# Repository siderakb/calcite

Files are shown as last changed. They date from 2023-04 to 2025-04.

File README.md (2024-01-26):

# Calcite

calcite52

Kailh Choc V1 (aka PG1350) low profile switches ortho keyboard, includes PCB and CNC/3DP case, inspired by [ARTSEY](https://artsey.io/), [Home row mods](https://precondition.github.io/home-row-mods) and Preonic/Planck keyboard. 

> The keycap in the above picture is from Keychron K1 v2.

## Note

Gerber, BOM and CPL files are generated by [KiCad JLCPCB Tools](https://github.com/Bouni/kicad-jlcpcb-tools) plugin.  

I use [KiCAD KLE Placer](https://github.com/zykrah/kicad-kle-placer) plugin to automatically place switch footprints.

If `key-switches.pretty` folder is empty, use `git submodule update --init` to clone submodule.

## Disclaimer

These files are provided without warranty of any kind.  
It is recommended to check yourself before manufacturing and use.

For the full statement, plase see [LICENSE](./LICENSE).

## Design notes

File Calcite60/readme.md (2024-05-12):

# Calcite60



A 60 keys ortho Kailh Choc V1 keyboard.

- Preonic V3 compatible (Mounting holes, USB and RESET button).
- Kailh Choc V1 low profile switches (PG1350), optional 2U keys.
- USB Type-C with ESD protection and resettable fuse.
- RP2040 ARM MCU, 16MB external flash.
- One configurable monochrome LED indicator.
- Powered by [QMK](https://github.com/qmk/qmk_firmware) firmware.
- Support [Vial](https://get.vial.today), edit keymap and configure keyboard in real time.
- JLCPCB's PCBA service available.

## PCB

Online preview available [here](https://kicanvas.org/?github=https%3A%2F%2Fgithub.com%2Fsiderakb%2Fcalcite%2Ftree%2Fmain%2FCalcite60%2Fpcb), powered by [KiCanvas](https://kicanvas.org/)

| | Preview |
| --- | :---: |
| Front  |  |
| Back |  |
| Layers |  |

### Board Characteristics

- Copper layer count: 2
- Board thickness: 1.6 mm
- Board overall dimensions: 226 mm x 94.15 mm
- Min track/spacing: 0.13 mm / 0.13 mm
- Min hole diameter: 0.3 mm
- Castellated pads: No
- Edge card connectors: No
- Plated board edge: No

## Screw

- 4* M2x2~4, 90° flat head

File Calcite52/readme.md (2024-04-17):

# Calcite52

calcite52

- 52 keys ortho keyboard.
- Kailh Choc V1 low profile switches (PG1350).
- USB Type-C with ESD protection and resettable fuse.
- RP2040 ARM MCU, 16MB external flash.
- One configurable monochrome LED indicator.
- M2 screw mounting holes.
- USB D+/- pads for debugging.
- Powered by [QMK](https://github.com/qmk/qmk_firmware) firmware.
- Support [Vial](https://get.vial.today), edit keymap and configure keyboard in real time.
- JLCPCB's PCBA service available.

## PCB

PCB online preview avaliable [here](https://kicanvas.org/?github=https%3A%2F%2Fgithub.com%2Fsiderakb%2Fcalcite%2Ftree%2Fmain%2FCalcite52%2Fpcb), powered by KiCanvas.

| | Preview |
| :----: | :---: |
| Front  |  |
|  Back  |  |
| Layers |  |

### Board Characteristics

- Copper layer count: 2
- Board thickness: 1.6 mm
- Board overall dimensions: 231.14 mm x 97.79 mm
- Min track/spacing: 0.13 mm / 0.13 mm
- Min hole diameter: 0.3 mm
- Castellated pads: No
- Edge card connectors: No
- Plated board edge: No

## Case

- CNC: Designed using [onshape](https://cad.onshape.com/documents/40c7e2089f3d168efe6af68a/w/3670640f6bf03c896decab1c/e/fe064372e5ac08dff53a3881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). I order aluminum 6061 + bead blast + anodized from PCBWay around 60 USD (June 2023).
- 3D Printing: Designed using FreeCAD. Please note that the 3D printed casing will bend easily and is not recommended.

## Firmware

Vial QMK firmware is available in [siderakb/vial-qmk repo](https://github.com/siderakb/vial-qmk/tree/siderakb/main/keyboards/siderakb/calcite52) (*siderakb/main* branch).

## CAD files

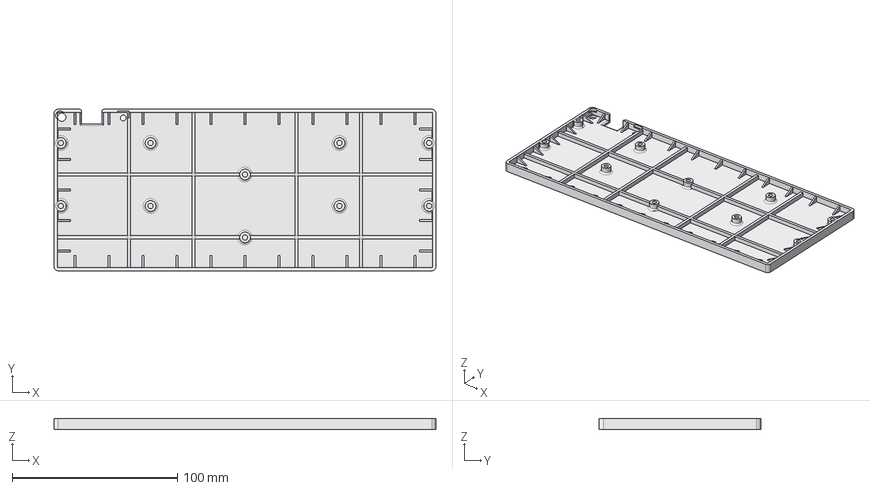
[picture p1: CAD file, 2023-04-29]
Calcite52/case/3dp/Calcite52_3dp_case.FCStd
231.1 x 97.8 x 6.50 mm

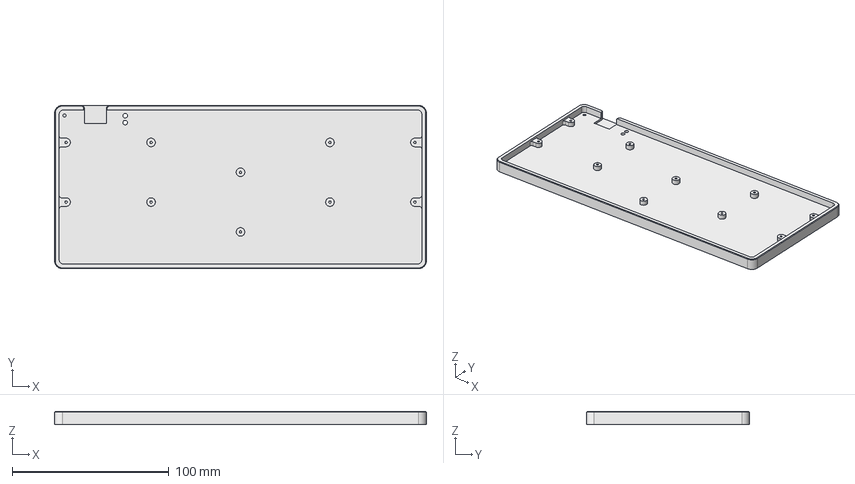
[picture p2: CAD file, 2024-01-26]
Calcite52/case/cnc/Calcite52_cnc_case.step
237.6 x 104.3 x 8.50 mm

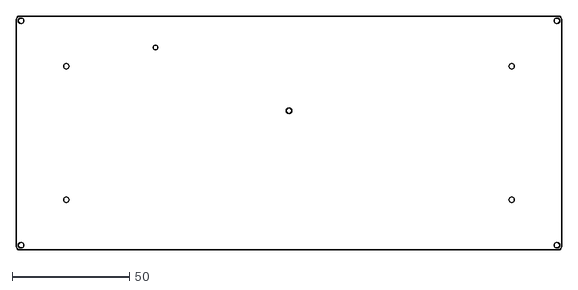
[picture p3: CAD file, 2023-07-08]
Calcite60/case/calcite60_case_bottom.dxf
232.8 x 99.8

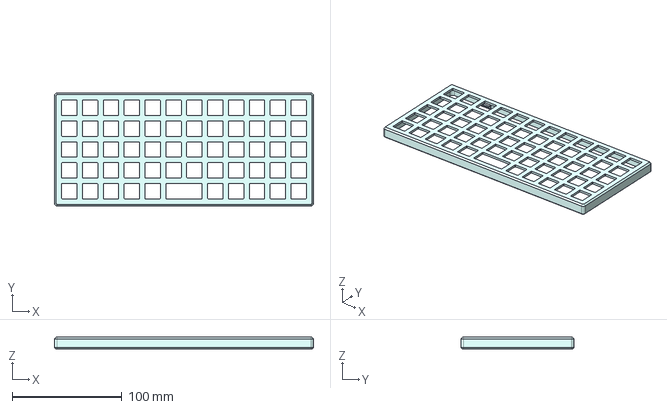
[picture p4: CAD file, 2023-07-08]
Calcite60/case/calcite60_case_top.step
236.0 x 103.0 x 10.5 mm

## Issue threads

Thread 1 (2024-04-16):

Footprints for tactile switches

gaexpa1, 2024-04-16:
The footprint SW_SPST_B3U-1000P is incompatible with the TS-1064S-A1B2-D4.
B3U-1000P-B?

ziteh, 2024-04-17:
You are right, this footprint without boss, the correct part should be B3U-1000P or TS-1064S***A***

ziteh, 2024-05-27:
Fixed in 1e7c8a413dfbfd1b928f15de38907081ed8602bb

Close inactive issue, and please feel free to reopen it if needed : )

Closed 2024-05-27.

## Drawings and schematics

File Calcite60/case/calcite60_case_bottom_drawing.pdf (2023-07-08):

2
1

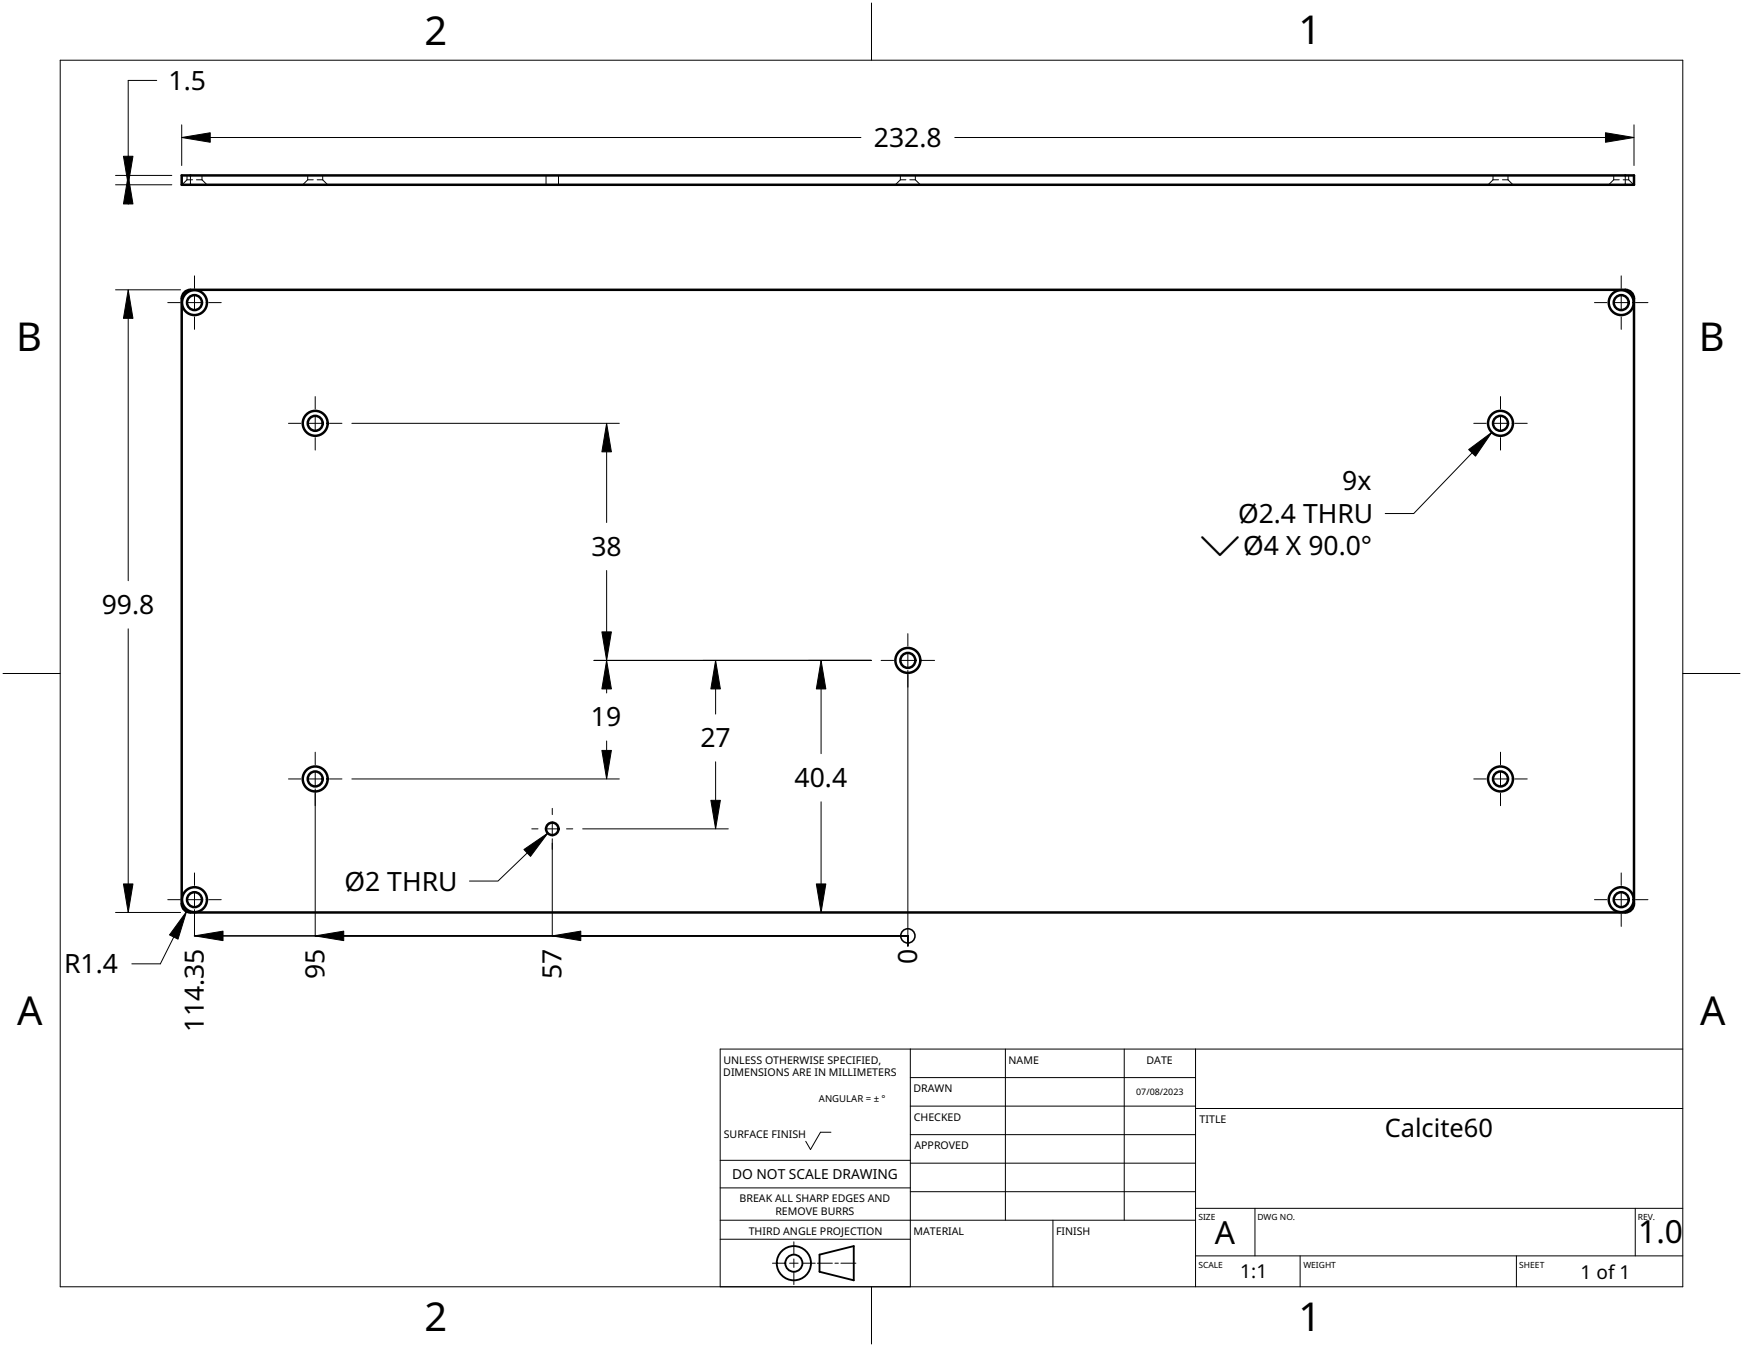
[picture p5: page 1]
MATERIAL; FINISH; Ø2 THRU; 9x Ø2.4 THRU Ø4 X 90.0°

UNLESS OTHERWISE SPECIFIED, DIMENSIONS ARE IN MILLIMETERS ANGULAR = ± ° SURFACE FINISH | | NAME | DATE

DRAWN | | 07/08/2023

CHECKED | | | TITLE Calcite60

APPROVED

DO NOT SCALE DRAWING

BREAK ALL SHARP EDGES AND

REMOVE BURRS
THIRD ANGLE PROJECTION

SIZE A | DWG NO. | REV. 1.0

SCALE 1:1 | WEIGHT | SHEET 1 of 1

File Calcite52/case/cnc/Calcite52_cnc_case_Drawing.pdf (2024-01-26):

2
1

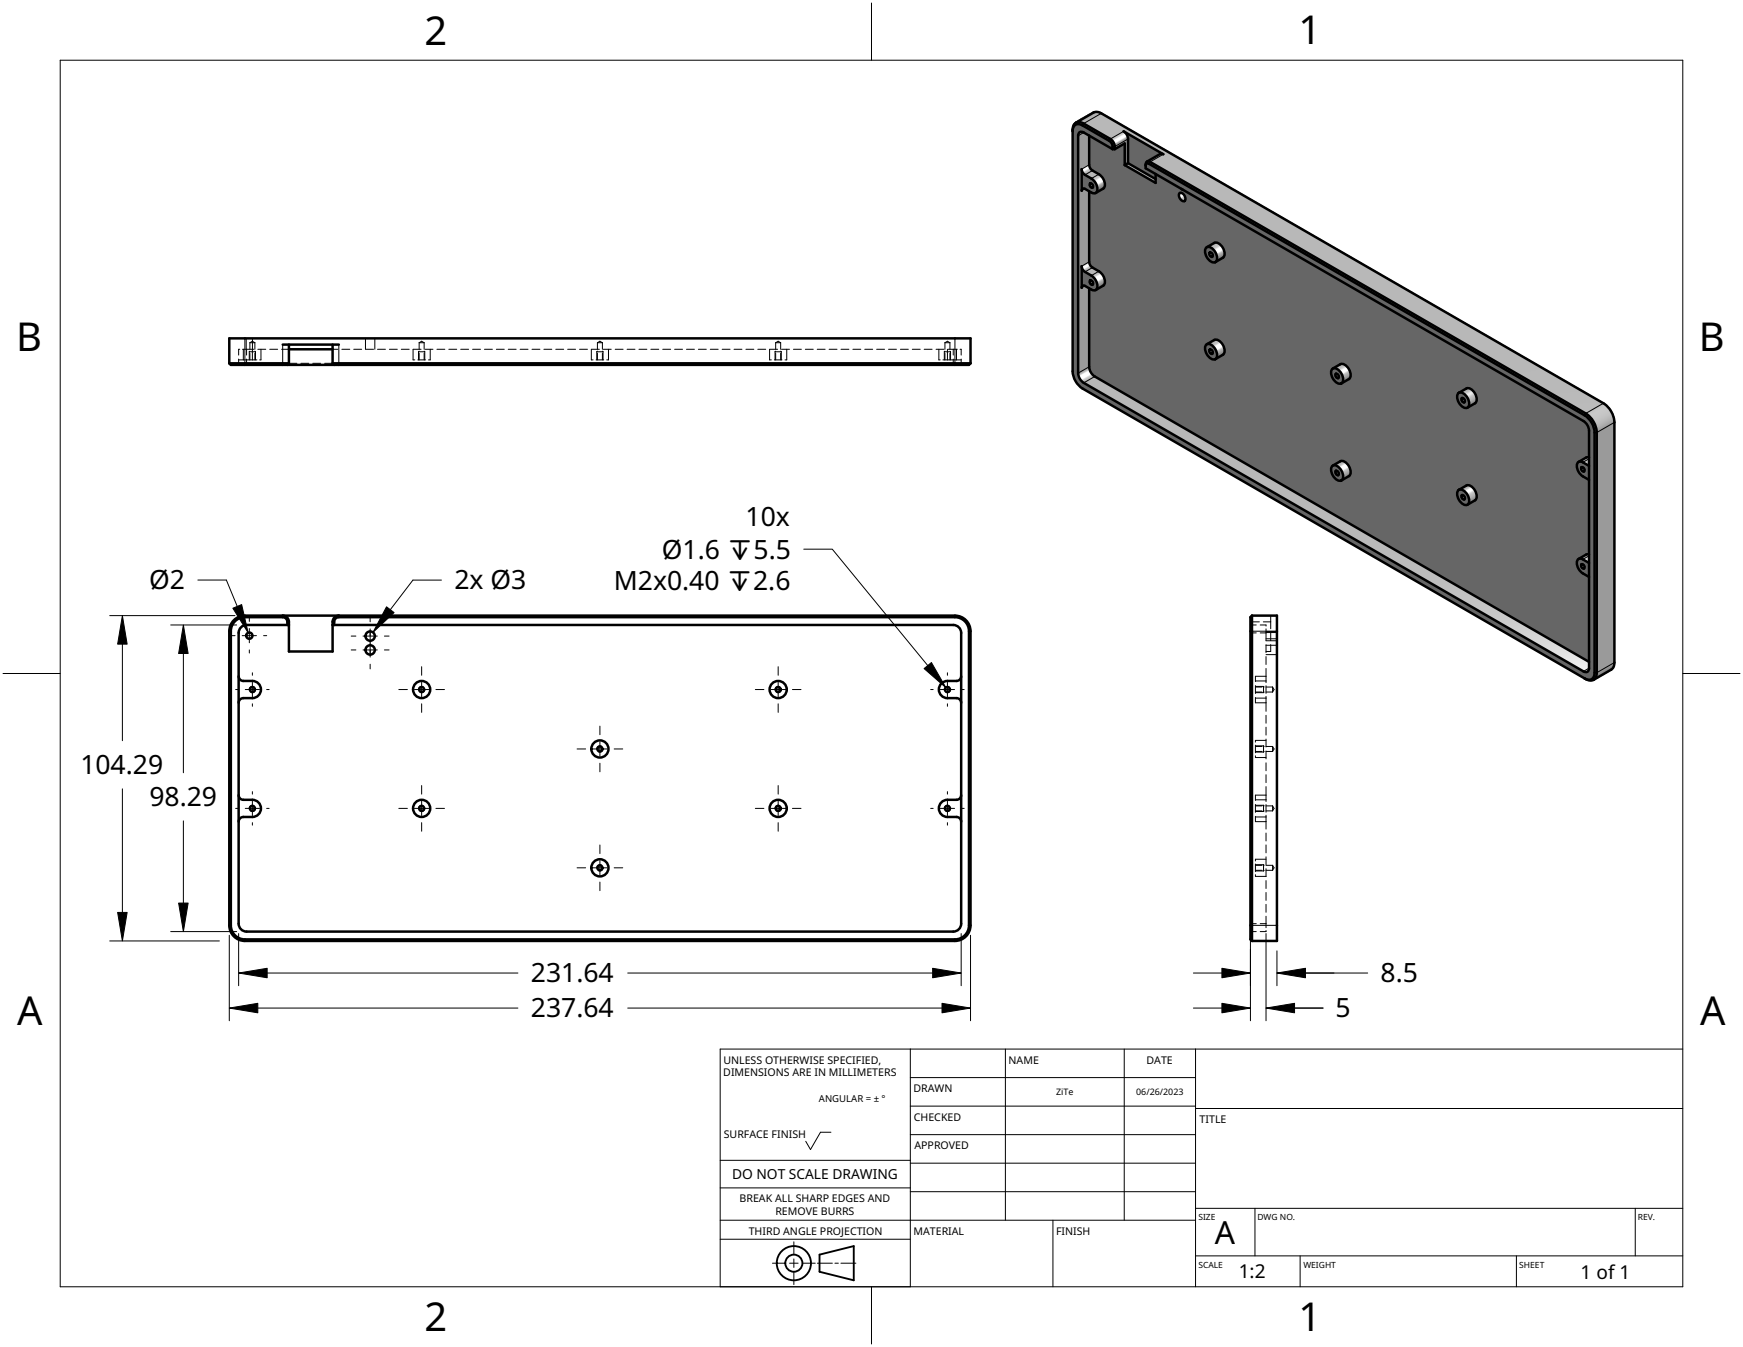
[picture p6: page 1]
MATERIAL; FINISH

UNLESS OTHERWISE SPECIFIED, DIMENSIONS ARE IN MILLIMETERS ANGULAR = ± ° SURFACE FINISH | | NAME | DATE

DRAWN | ZiTe | 06/26/2023

CHECKED | | | TITLE

APPROVED

DO NOT SCALE DRAWING

BREAK ALL SHARP EDGES AND

REMOVE BURRS
THIRD ANGLE PROJECTION

SIZE A | DWG NO. | REV.

SCALE 1:2 | WEIGHT | SHEET 1 of 1

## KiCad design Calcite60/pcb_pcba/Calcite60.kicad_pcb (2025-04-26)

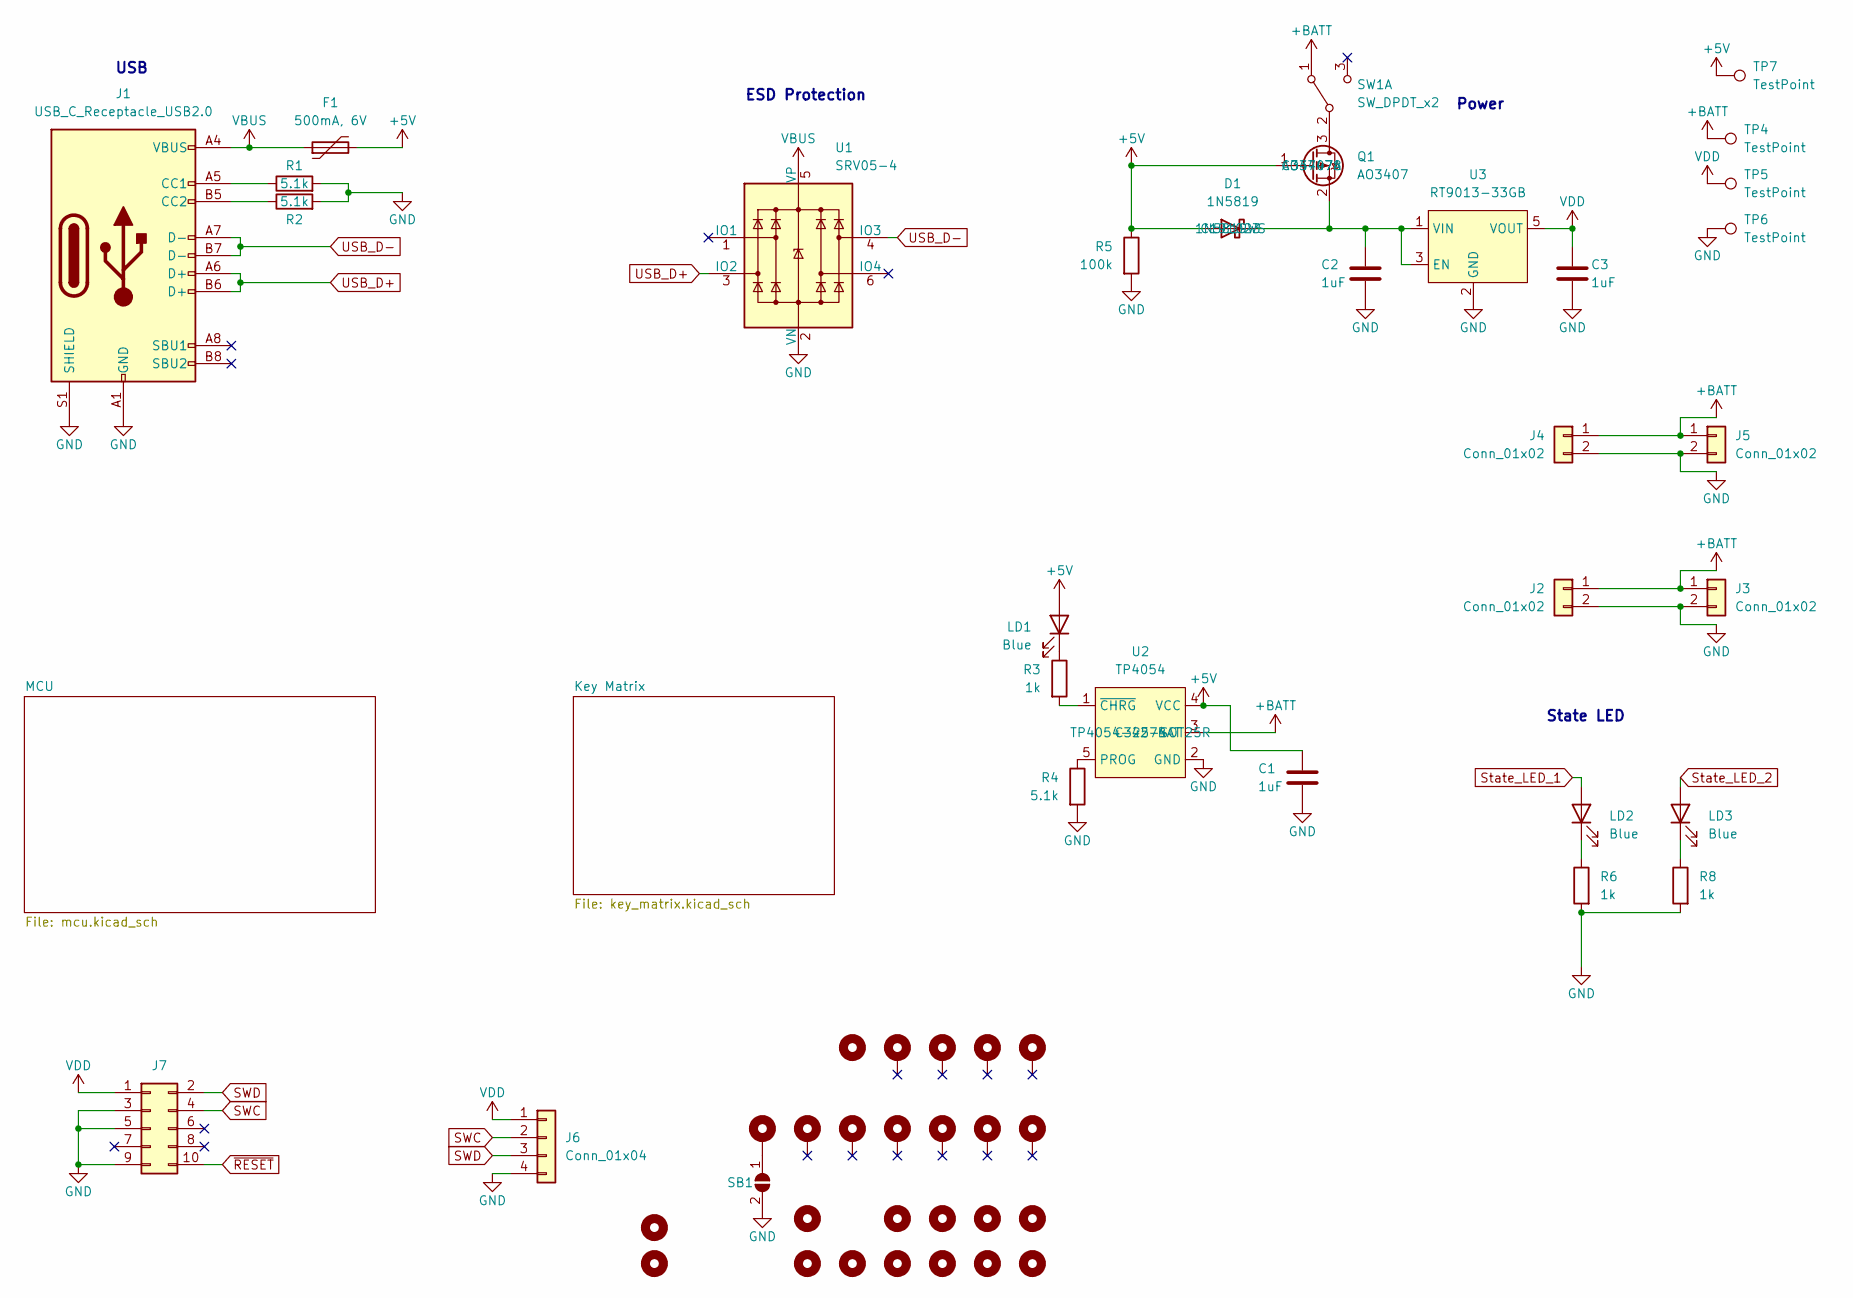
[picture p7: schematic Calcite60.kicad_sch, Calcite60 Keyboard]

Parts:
C1, C2, C3: 1uF; C_0603_1608Metric; MFR. Part # CL10A105KB8NNNC; LCSC C15849
D1: 1N5819; D_SOD-323_HandSoldering; MFR. Part # 1N5819WS; LCSC C191023
F1: 500mA, 6V; Fuse_0805_2012Metric; MFR. Part # SMD0805B050TF; LCSC C269104
H1, H2, H4, H6, H8, H10, H12, H14, H15, H16, H17: MountingHole; MountingWuerth_M2; MFR. Part # 9774025243R; LCSC C9900035855
H5, H18, H19, H20, H21, H22, H23, H24, H25, H26: MountingHole; mouse_bite
H7, H9, H11, H13: MountingHole; MountingHale_M2
J1: USB_C_Receptacle_USB2.0; USB_C_Receptacle_HRO_TYPE-C-31-M-12; MFR. Part # TYPE-C-31-M-12; LCSC C165948
J2, J4: Conn_01x02; PinHeader_1x02_P2.54mm_Vertical
J3, J5: Conn_01x02; JST_PH_S2B-PH-K_1x02_P2.00mm_Horizontal
J6: Conn_01x04; PinHeader_1x04_P2.54mm_Vertical
J7: Conn_02x05_Counter_Clockwise; 10pin SWD
LD1, LD2, LD3: Blue; LED_0603_1608Metric; MFR. Part # 19-217/GHC-YR1S2/3T; LCSC C72043
Q1: AO3407; SOT-23; MFR. Part # AO3407A; LCSC C347478
R1, R2, R4: 5.1k; R_0603_1608Metric; MFR. Part # 0603WAF5101T5E; LCSC C23186
R3, R6, R8: 1k; R_0603_1608Metric; MFR. Part # 0603WAF1001T5E; LCSC C21190
R5: 100k; R_0603_1608Metric; MFR. Part # 0603WAF1003T5E; LCSC C25803
SB1: SolderJumper_2_Open; SolderJumper-2_P1.3mm_Open_TrianglePad1.0x1.5mm
SW1: SW_DPDT_x2; 9_3.5_3.5 Switch
TP4, TP5, TP6, TP7: TestPoint; TestPoint_Pad_D1.5mm
U1: SRV05-4; SOT-23-6; MFR. Part # SRV05-4-P-T7; LCSC C85364
U2: TP4054; SOT-23-5; MFR. Part # TP4054-42-SOT25R; LCSC C32574
U3: RT9013-33GB; SOT-23-5; MFR. Part # TPRT9013-33GB; LCSC C587158

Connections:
+5V: C1.1, D1.2 (A), F1.2, LD1.2 (A), Q1.1 (G), R5.1, TP7.1, U2.4 (VCC); also elsewhere on the board
+BATT: J2.1, J3.1, J4.1, J5.1, SW1.1 (A), TP4.1, U2.3 (BAT); also elsewhere on the board
GND: C1.2, C2.2, C3.2, J1.A1 (GND), J1.A12 (GND), J1.B1 (GND), J1.B12 (GND), J1.S1 (SHIELD), J2.2, J3.2, J4.2, J5.2, J6.4, J7.3, J7.5, J7.9, R1.2, R2.2, R4.2, R5.2, R6.2, R8.2, SB1.2 (B), TP6.1, U1.2 (VN), U2.2 (GND), U3.2 (GND); also elsewhere on the board
unnamed: C2.1, D1.1 (K), Q1.2 (S), U3.1 (VIN), U3.3 (EN)
unnamed: J1.A5 (CC1), R1.1
unnamed: J1.B5 (CC2), R2.1
unnamed: LD1.1 (K), R3.1
unnamed: LD2.1 (K), R6.1
unnamed: LD3.1 (K), R8.1
unnamed: Q1.3 (D), SW1.2 (B)
unnamed: H1.1, SB1.1 (A)
unnamed: R4.1, U2.5 (PROG)
unnamed: R3.2, U2.1 (~CHRG)
SWC: J6.2, J7.4; also elsewhere on the board
SWD: J6.3, J7.2; also elsewhere on the board
State_LED_1: LD2.2 (A); also elsewhere on the board
State_LED_2: LD3.2 (A); also elsewhere on the board
USB_D+: J1.A6 (D+), J1.B6 (D+), U1.3 (IO2); also elsewhere on the board
USB_D-: J1.A7 (D-), J1.B7 (D-), U1.4 (IO3); also elsewhere on the board
VBUS: F1.1, J1.A4 (VBUS), J1.A9 (VBUS), J1.B4 (VBUS), J1.B9 (VBUS), U1.5 (VP)
VDD: C3.1, J6.1, J7.1, TP5.1, U3.5 (VOUT); also elsewhere on the board
~RESET: J7.10; also elsewhere on the board

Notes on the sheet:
ESD Protection
State LED
USB
Power

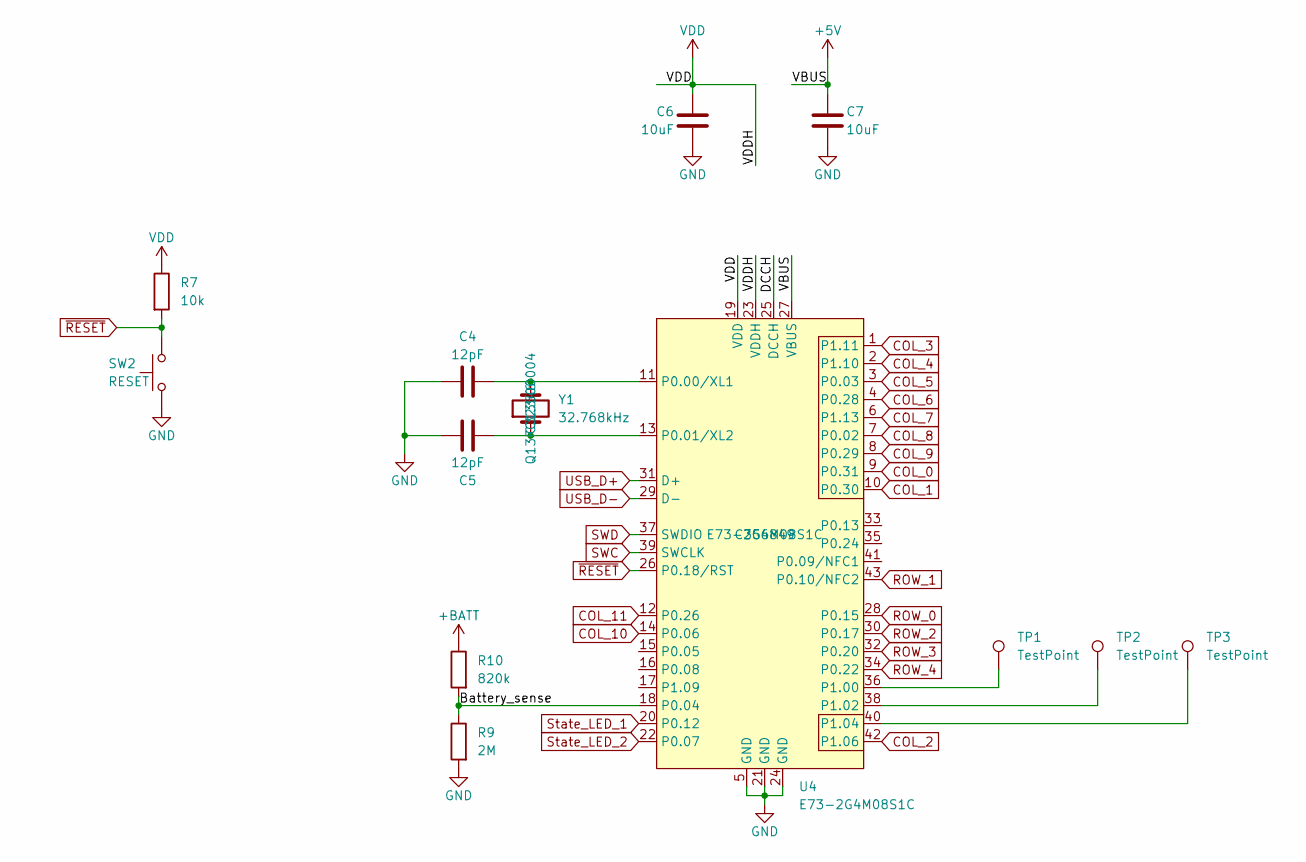
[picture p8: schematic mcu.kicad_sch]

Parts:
C4, C5: 12pF; C_0603_1608Metric; MFR. Part # CL10C120JB8NNNC; LCSC C38523
C6, C7: 10uF; C_0603_1608Metric; MFR. Part # CL10A106KP8NNNC; LCSC C19702
R7: 10k; R_0603_1608Metric; MFR. Part # 0603WAF1002T5E; LCSC C25804
R9: 2M; R_0603_1608Metric; MFR. Part # 0603WAF2004T5E; LCSC C22976
R10: 820k; R_0603_1608Metric; MFR. Part # 0603WAF8203T5E; LCSC C23252
SW2: RESET; SW_SPST_B3U-1000P; MFR. Part # TS-1064SA-A1B2-D4; LCSC C7464577
TP1, TP2, TP3: TestPoint; TestPoint_Pad_D1.5mm
U4: E73-2G4M08S1C; E73-2G4M08S1C nRF52840 (PCBA soldering); MFR. Part # E73-2G4M08S1C; LCSC C356849
Y1: 32.768kHz; Crystal_SMD_3215-2Pin_3.2x1.5mm; MFR. Part # Q13FC13500004; LCSC C32346

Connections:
+5V: C7.1, U4.27 (VBUS); also elsewhere on the board
+BATT: R10.1; also elsewhere on the board
/MCU/Battery_sense: R9.1, R10.2, U4.18 (P0.04)
/MCU/DCCH: U4.25 (DCCH)
COL_0: U4.9 (P0.31); also elsewhere on the board
COL_1: U4.10 (P0.30); also elsewhere on the board
COL_2: U4.42 (P1.06); also elsewhere on the board
COL_3: U4.1 (P1.11); also elsewhere on the board
COL_4: U4.2 (P1.10); also elsewhere on the board
COL_5: U4.3 (P0.03); also elsewhere on the board
COL_6: U4.4 (P0.28); also elsewhere on the board
COL_7: U4.6 (P1.13); also elsewhere on the board
COL_8: U4.7 (P0.02); also elsewhere on the board
COL_9: U4.8 (P0.29); also elsewhere on the board
COL_10: U4.14 (P0.06); also elsewhere on the board
COL_11: U4.12 (P0.26); also elsewhere on the board
GND: C4.2, C5.1, C6.2, C7.2, R9.2, SW2.1, U4.5 (GND), U4.21 (GND), U4.24 (GND); also elsewhere on the board
unnamed: C4.1, U4.11 (P0.00/XL1), Y1.2
unnamed: C5.2, U4.13 (P0.01/XL2), Y1.1
unnamed: TP1.1, U4.36 (P1.00)
unnamed: TP2.1, U4.38 (P1.02)
unnamed: TP3.1, U4.40 (P1.04)
ROW_0: U4.28 (P0.15); also elsewhere on the board
ROW_1: U4.43 (P0.10/NFC2); also elsewhere on the board
ROW_2: U4.30 (P0.17); also elsewhere on the board
ROW_3: U4.32 (P0.20); also elsewhere on the board
ROW_4: U4.34 (P0.22); also elsewhere on the board
SWC: U4.39 (SWCLK); also elsewhere on the board
SWD: U4.37 (SWDIO); also elsewhere on the board
State_LED_1: U4.20 (P0.12); also elsewhere on the board
State_LED_2: U4.22 (P0.07); also elsewhere on the board
USB_D+: U4.31 (D+); also elsewhere on the board
USB_D-: U4.29 (D-); also elsewhere on the board
VDD: C6.1, R7.1, U4.19 (VDD), U4.23 (VDDH); also elsewhere on the board
~RESET: R7.2, SW2.2, U4.26 (P0.18/RST); also elsewhere on the board

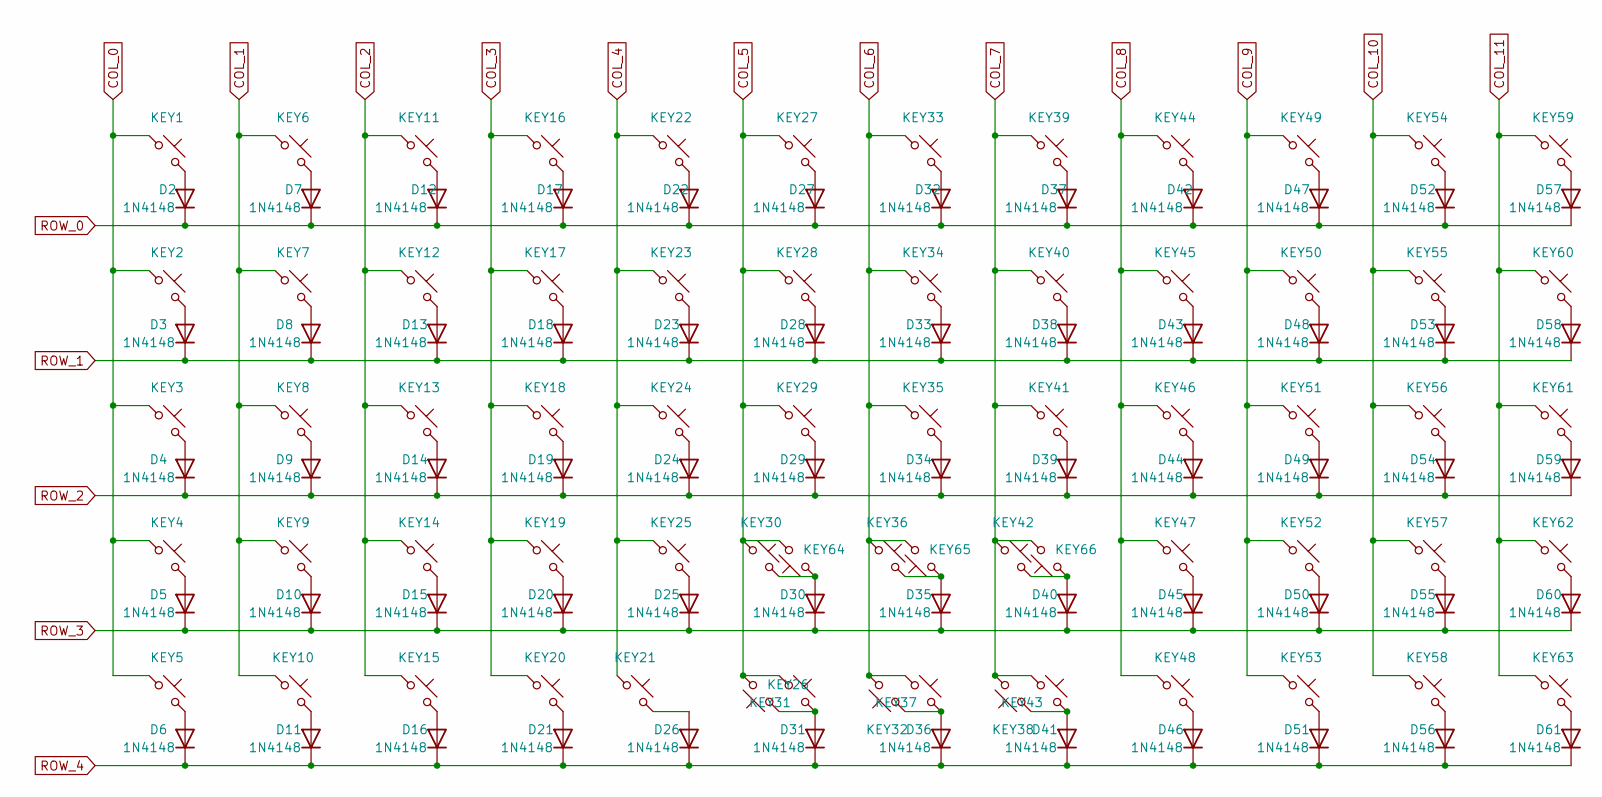
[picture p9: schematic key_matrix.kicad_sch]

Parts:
D2, D3, D4, D5, D6, D7, D8, D9, D10, D11, D12, D13, D14, D15, D16, D17, D18, D19, D20, D21, D22, D23, D24, D25, D26, D27, D28, D29, D30, D31, D32, D33, D34, D35, D36, D37, D38, D39, D40, D41, D42, D43, D44, D45, D46, D47, D48, D49, D50, D51, D52, D53, D54, D55, D56, D57, D58, D59, D60, D61: 1N4148; D_SOD-123; MFR. Part # 1N4148W; LCSC C81598
KEY1, KEY2, KEY3, KEY4, KEY5, KEY6, KEY7, KEY8, KEY9, KEY10, KEY11, KEY12, KEY13, KEY14, KEY15, KEY16, KEY17, KEY18, KEY19, KEY20, KEY21, KEY22, KEY23, KEY24, KEY25, KEY26, KEY27, KEY28, KEY29, KEY30, KEY31, KEY32, KEY33, KEY34, KEY35, KEY36, KEY37, KEY38, KEY39, KEY40, KEY41, KEY42, KEY43, KEY44, KEY45, KEY46, KEY47, KEY48, KEY49, KEY50, KEY51, KEY52, KEY53, KEY54, KEY55, KEY56, KEY57, KEY58, KEY59, KEY60, KEY61, KEY62, KEY63, KEY64, KEY65, KEY66: SW_Push_45deg; SW_Kailh_Choc_V1_THT_nSilk

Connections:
COL_0: KEY1.1, KEY2.1, KEY3.1, KEY4.1, KEY5.1; also elsewhere on the board
COL_1: KEY6.1, KEY7.1, KEY8.1, KEY9.1, KEY10.1; also elsewhere on the board
COL_2: KEY11.1, KEY12.1, KEY13.1, KEY14.1, KEY15.1; also elsewhere on the board
COL_3: KEY16.1, KEY17.1, KEY18.1, KEY19.1, KEY20.1; also elsewhere on the board
COL_4: KEY21.1, KEY22.1, KEY23.1, KEY24.1, KEY25.1; also elsewhere on the board
COL_5: KEY26.2, KEY27.1, KEY28.1, KEY29.1, KEY30.1, KEY31.1, KEY64.2; also elsewhere on the board
COL_6: KEY32.2, KEY33.1, KEY34.1, KEY35.1, KEY36.1, KEY37.1, KEY65.2; also elsewhere on the board
COL_7: KEY38.2, KEY39.1, KEY40.1, KEY41.1, KEY42.1, KEY43.1, KEY66.2; also elsewhere on the board
COL_8: KEY44.1, KEY45.1, KEY46.1, KEY47.1, KEY48.1; also elsewhere on the board
COL_9: KEY49.1, KEY50.1, KEY51.1, KEY52.1, KEY53.1; also elsewhere on the board
COL_10: KEY54.1, KEY55.1, KEY56.1, KEY57.1, KEY58.1; also elsewhere on the board
COL_11: KEY59.1, KEY60.1, KEY61.1, KEY62.1, KEY63.1; also elsewhere on the board
unnamed: D2.2 (A), KEY1.2
unnamed: D3.2 (A), KEY2.2
unnamed: D4.2 (A), KEY3.2
unnamed: D5.2 (A), KEY4.2
unnamed: D6.2 (A), KEY5.2
unnamed: D7.2 (A), KEY6.2
unnamed: D8.2 (A), KEY7.2
unnamed: D9.2 (A), KEY8.2
unnamed: D10.2 (A), KEY9.2
unnamed: D11.2 (A), KEY10.2
unnamed: D12.2 (A), KEY11.2
unnamed: D13.2 (A), KEY12.2
unnamed: D14.2 (A), KEY13.2
unnamed: D15.2 (A), KEY14.2
unnamed: D16.2 (A), KEY15.2
unnamed: D17.2 (A), KEY16.2
unnamed: D18.2 (A), KEY17.2
unnamed: D19.2 (A), KEY18.2
unnamed: D20.2 (A), KEY19.2
unnamed: D21.2 (A), KEY20.2
unnamed: D22.2 (A), KEY22.2
unnamed: D23.2 (A), KEY23.2
unnamed: D24.2 (A), KEY24.2
unnamed: D25.2 (A), KEY25.2
unnamed: D26.2 (A), KEY21.2
unnamed: D27.2 (A), KEY27.2
unnamed: D28.2 (A), KEY28.2
unnamed: D29.2 (A), KEY29.2
unnamed: D30.2 (A), KEY30.2, KEY64.1
unnamed: D31.2 (A), KEY26.1, KEY31.2
unnamed: D32.2 (A), KEY33.2
unnamed: D33.2 (A), KEY34.2
unnamed: D34.2 (A), KEY35.2
unnamed: D35.2 (A), KEY36.2, KEY65.1
unnamed: D36.2 (A), KEY32.1, KEY37.2
unnamed: D37.2 (A), KEY39.2
unnamed: D38.2 (A), KEY40.2
unnamed: D39.2 (A), KEY41.2
unnamed: D40.2 (A), KEY42.2, KEY66.1
unnamed: D41.2 (A), KEY38.1, KEY43.2
unnamed: D42.2 (A), KEY44.2
unnamed: D43.2 (A), KEY45.2
unnamed: D44.2 (A), KEY46.2
unnamed: D45.2 (A), KEY47.2
unnamed: D46.2 (A), KEY48.2
unnamed: D47.2 (A), KEY49.2
unnamed: D48.2 (A), KEY50.2
unnamed: D49.2 (A), KEY51.2
unnamed: D50.2 (A), KEY52.2
unnamed: D51.2 (A), KEY53.2
unnamed: D52.2 (A), KEY54.2
unnamed: D53.2 (A), KEY55.2
unnamed: D54.2 (A), KEY56.2
unnamed: D55.2 (A), KEY57.2
unnamed: D56.2 (A), KEY58.2
unnamed: D57.2 (A), KEY59.2
unnamed: D58.2 (A), KEY60.2
unnamed: D59.2 (A), KEY61.2
unnamed: D60.2 (A), KEY62.2
unnamed: D61.2 (A), KEY63.2
ROW_0: D2.1 (K), D7.1 (K), D12.1 (K), D17.1 (K), D22.1 (K), D27.1 (K), D32.1 (K), D37.1 (K), D42.1 (K), D47.1 (K), D52.1 (K), D57.1 (K); also elsewhere on the board
ROW_1: D3.1 (K), D8.1 (K), D13.1 (K), D18.1 (K), D23.1 (K), D28.1 (K), D33.1 (K), D38.1 (K), D43.1 (K), D48.1 (K), D53.1 (K), D58.1 (K); also elsewhere on the board
ROW_2: D4.1 (K), D9.1 (K), D14.1 (K), D19.1 (K), D24.1 (K), D29.1 (K), D34.1 (K), D39.1 (K), D44.1 (K), D49.1 (K), D54.1 (K), D59.1 (K); also elsewhere on the board
ROW_3: D5.1 (K), D10.1 (K), D15.1 (K), D20.1 (K), D25.1 (K), D30.1 (K), D35.1 (K), D40.1 (K), D45.1 (K), D50.1 (K), D55.1 (K), D60.1 (K); also elsewhere on the board
ROW_4: D6.1 (K), D11.1 (K), D16.1 (K), D21.1 (K), D26.1 (K), D31.1 (K), D36.1 (K), D41.1 (K), D46.1 (K), D51.1 (K), D56.1 (K), D61.1 (K); also elsewhere on the board

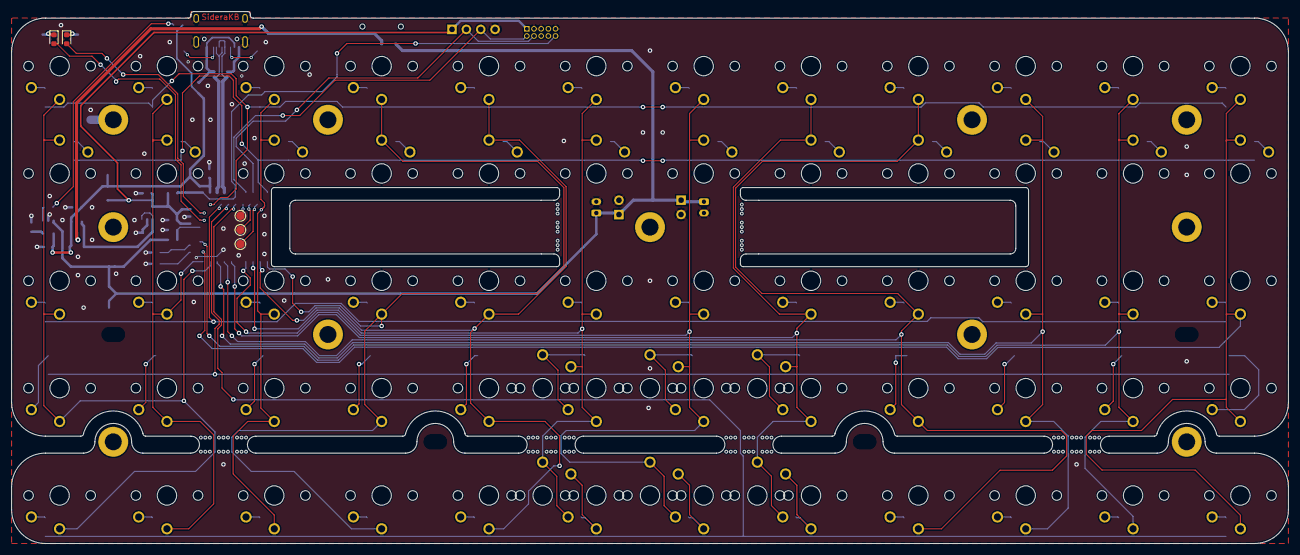
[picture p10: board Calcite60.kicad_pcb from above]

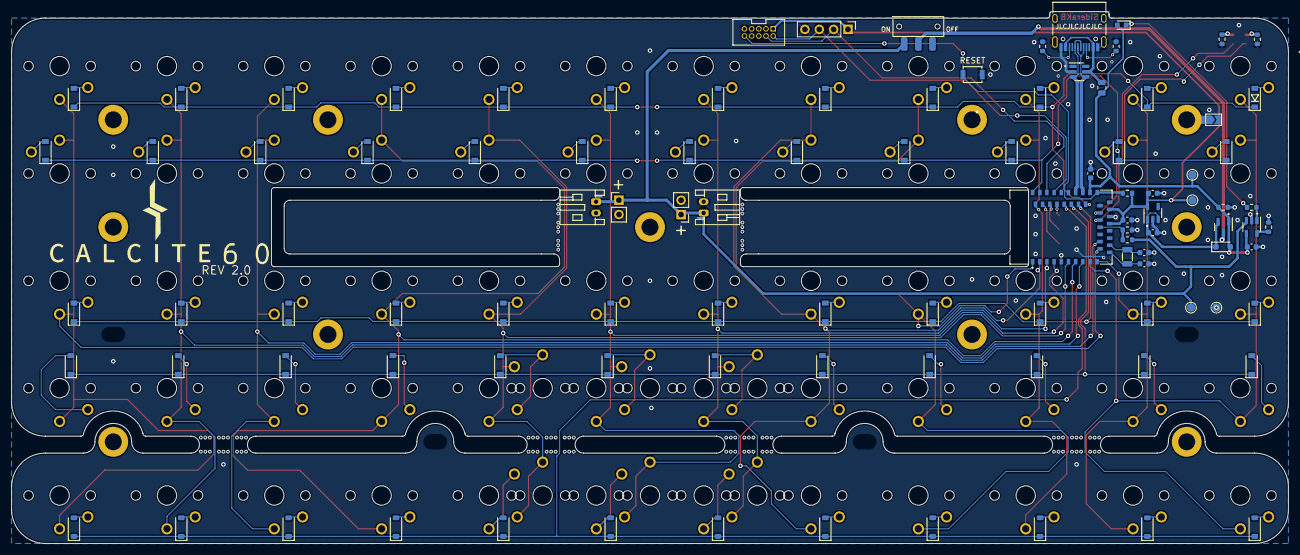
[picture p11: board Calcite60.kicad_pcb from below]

Board: 2 copper layers, 226.0 x 94.2 mm, 196 parts (111 on the bottom side), 105 nets.

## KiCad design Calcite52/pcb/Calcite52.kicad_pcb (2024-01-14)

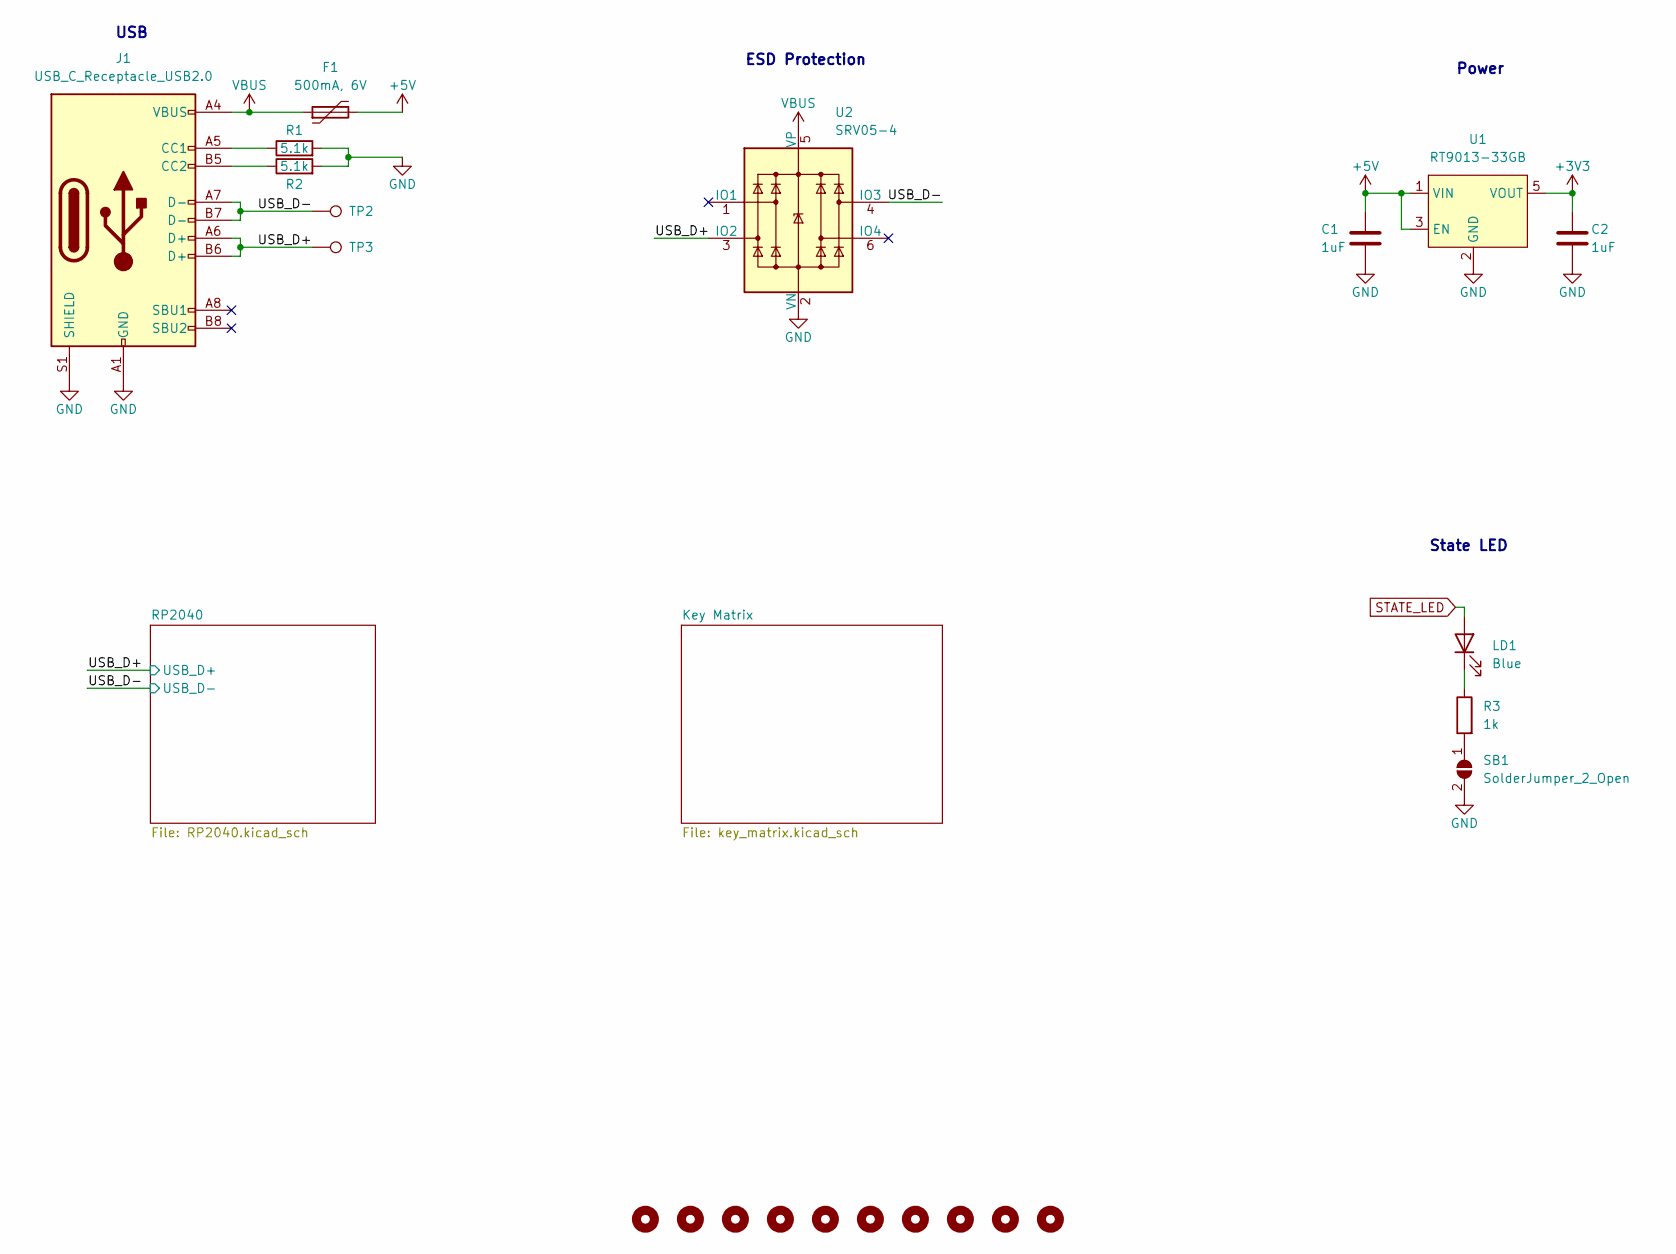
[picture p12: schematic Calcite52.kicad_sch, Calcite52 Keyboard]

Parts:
C1, C2: 1uF; C_0402_1005Metric; MFR. Part # CL05A105KA5NQNC; LCSC C52923
F1: 500mA, 6V; Fuse_0805_2012Metric; MFR. Part # SMD0805B050TF; LCSC C269104
H1, H2, H3, H4, H5, H6, H7, H8, H9, H10: MountingHole; MountingHole_2.2mm_M2
J1: USB_C_Receptacle_USB2.0; USB_C_Receptacle_HRO_TYPE-C-31-M-12; MFR. Part # TYPE-C-31-M-12; LCSC C165948
LD1: Blue; LED_0603_1608Metric; MFR. Part # 19-217/GHC-YR1S2/3T; LCSC C72043
R1, R2: 5.1k; R_0402_1005Metric; MFR. Part # 0402WGF5101TCE; LCSC C25905
R3: 1k; R_0402_1005Metric; MFR. Part # 0402WGF1001TCE; LCSC C11702
SB1: SolderJumper_2_Open; SolderJumper-2_P1.3mm_Open_TrianglePad1.0x1.5mm
TP2, TP3: TestPoint; TestPoint_Pad_1.5x1.5mm
U1: RT9013-33GB; SOT-23-5; MFR. Part # RT9013-33GB; LCSC C47773
U2: SRV05-4; SOT-23-6; MFR. Part # SRV05-4-P-T7; LCSC C85364

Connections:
+3V3: C2.1, U1.5 (VOUT); also elsewhere on the board
+5V: C1.1, F1.2, U1.1 (VIN), U1.3 (EN)
/USB_D+: J1.A6 (D+), J1.B6 (D+), TP3.1, U2.3 (IO2); also elsewhere on the board
/USB_D-: J1.A7 (D-), J1.B7 (D-), TP2.1, U2.4 (IO3); also elsewhere on the board
GND: C1.2, C2.2, J1.A1 (GND), J1.A12 (GND), J1.B1 (GND), J1.B12 (GND), J1.S1 (SHIELD), R1.2, R2.2, SB1.2 (B), U1.2 (GND), U2.2 (VN); also elsewhere on the board
unnamed: J1.A5 (CC1), R1.1
unnamed: J1.B5 (CC2), R2.1
unnamed: LD1.1 (K), R3.1
unnamed: R3.2, SB1.1 (A)
STATE_LED: LD1.2 (A); also elsewhere on the board
VBUS: F1.1, J1.A4 (VBUS), J1.A9 (VBUS), J1.B4 (VBUS), J1.B9 (VBUS), U2.5 (VP)

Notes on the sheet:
ESD Protection
State LED
USB
Power

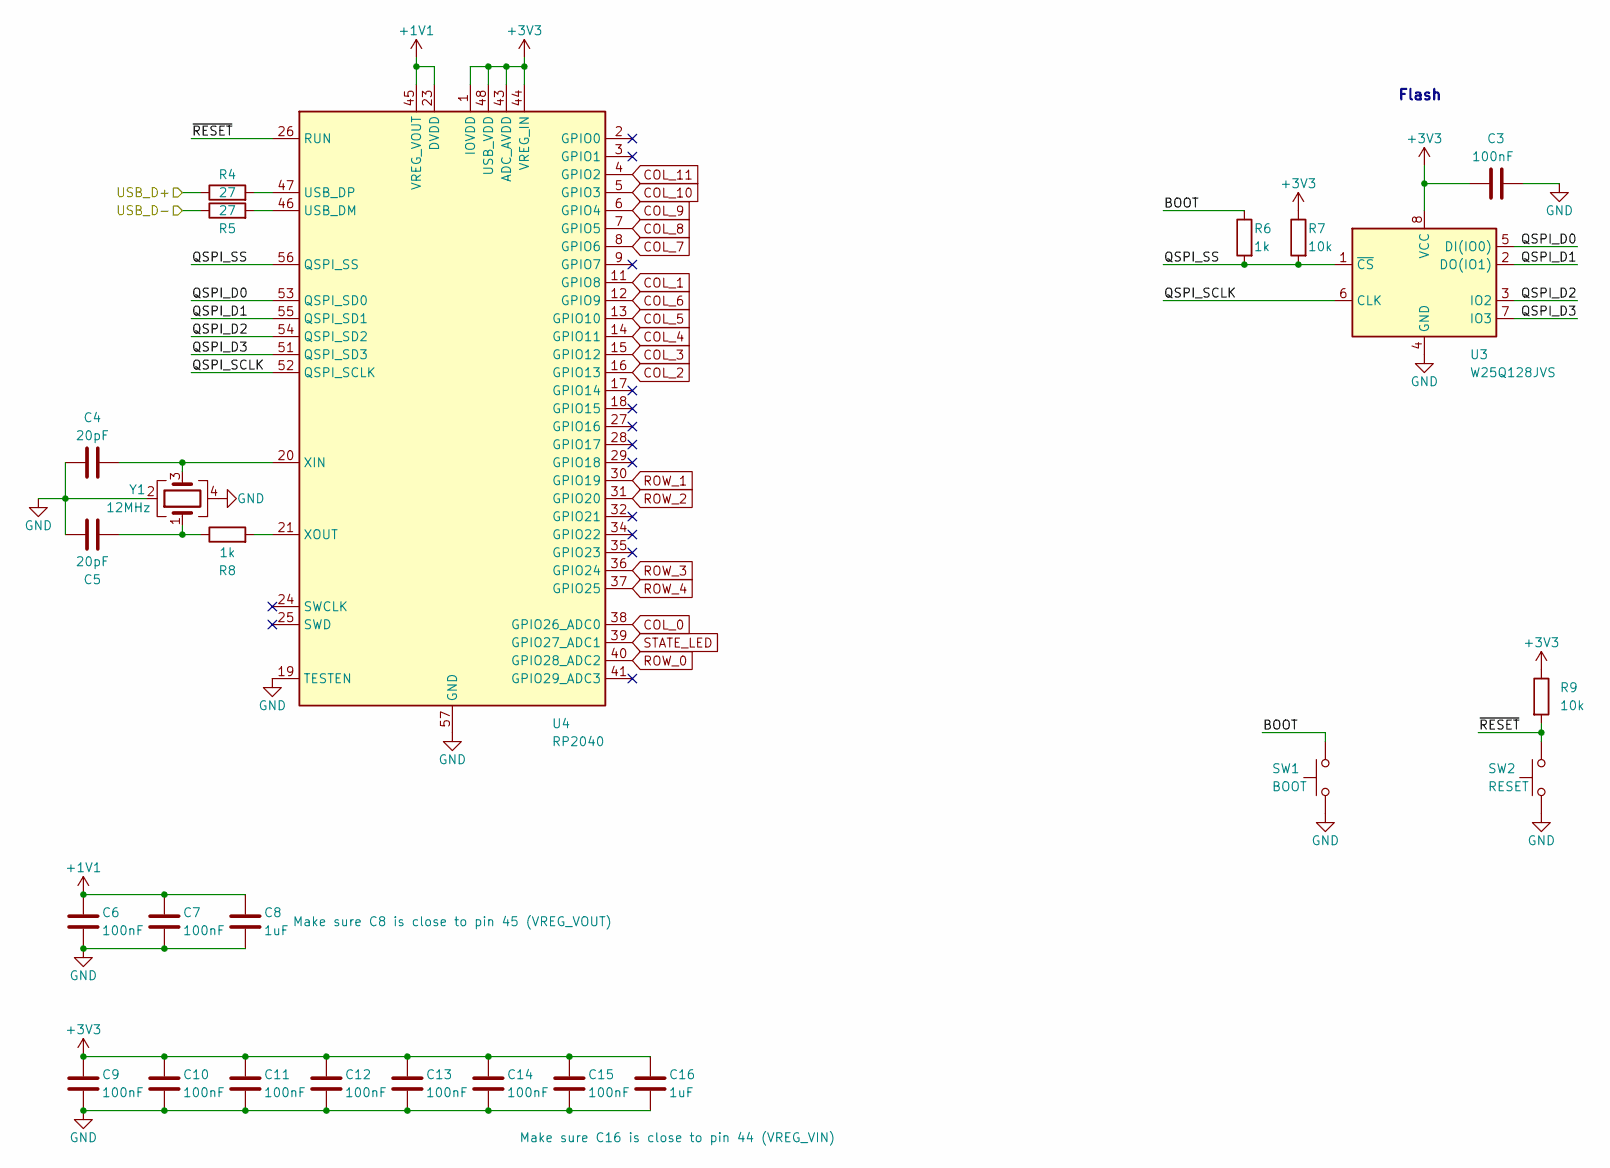
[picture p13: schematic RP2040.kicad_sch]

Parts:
C3, C6, C7, C9, C10, C11, C12, C13, C14, C15: 100nF; C_0402_1005Metric; MFR. Part # CL05B104KB54PNC; LCSC C307331
C4, C5: 20pF; C_0402_1005Metric; MFR. Part # 0402CG200J500NT; LCSC C1554
C8, C16: 1uF; C_0402_1005Metric; MFR. Part # CL05A105KA5NQNC; LCSC C52923
R4, R5: 27; R_0603_1608Metric; MFR. Part # 0603WAF270JT5E; LCSC C25190
R6, R8: 1k; R_0402_1005Metric; MFR. Part # 0402WGF1001TCE; LCSC C11702
R7, R9: 10k; R_0402_1005Metric; MFR. Part # 0402WGF1002TCE; LCSC C25744
SW1: BOOT; SW_SPST_CK_RS282G05A3; MFR. Part # GT-TC060B-H027-L1; LCSC C5117871
SW2: RESET; SW_SPST_CK_RS282G05A3; MFR. Part # GT-TC060B-H027-L1; LCSC C5117871
U3: W25Q128JVS; SOIC-8_5.23x5.23mm_P1.27mm; MFR. Part # W25Q128JVSIQ; LCSC C97521
U4: RP2040; QFN-56-1EP_7x7mm_P0.4mm_EP3.2x3.2mm; MFR. Part # RP2040; LCSC C2040
Y1: 12MHz; Crystal_SMD_3225-4Pin_3.2x2.5mm; MFR. Part # X322512MSB4SI; LCSC C9002

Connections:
+1V1: C6.1, C7.1, C8.1, U4.23 (DVDD), U4.45 (VREG_VOUT), U4.50 (DVDD)
+3V3: C3.1, C9.1, C10.1, C11.1, C12.1, C13.1, C14.1, C15.1, C16.1, R7.1, R9.1, U3.8 (VCC), U4.1 (IOVDD), U4.10 (IOVDD), U4.22 (IOVDD), U4.33 (IOVDD), U4.42 (IOVDD), U4.43 (ADC_AVDD), U4.44 (VREG_IN), U4.48 (USB_VDD), U4.49 (IOVDD); also elsewhere on the board
/RP2040/BOOT: R6.1, SW1.2
/RP2040/QSPI_D0: U3.5 (DI(IO0)), U4.53 (QSPI_SD0)
/RP2040/QSPI_D1: U3.2 (DO(IO1)), U4.55 (QSPI_SD1)
/RP2040/QSPI_D2: U3.3 (IO2), U4.54 (QSPI_SD2)
/RP2040/QSPI_D3: U3.7 (IO3), U4.51 (QSPI_SD3)
/RP2040/QSPI_SCLK: U3.6 (CLK), U4.52 (QSPI_SCLK)
/RP2040/QSPI_SS: R6.2, R7.2, U3.1 (~CS), U4.56 (QSPI_SS)
/RP2040/~RESET: R9.2, SW2.2, U4.26 (RUN)
/USB_D+: R4.1; also elsewhere on the board
/USB_D-: R5.1; also elsewhere on the board
COL_0: U4.38 (GPIO26_ADC0); also elsewhere on the board
COL_1: U4.11 (GPIO8); also elsewhere on the board
COL_2: U4.16 (GPIO13); also elsewhere on the board
COL_3: U4.15 (GPIO12); also elsewhere on the board
COL_4: U4.14 (GPIO11); also elsewhere on the board
COL_5: U4.13 (GPIO10); also elsewhere on the board
COL_6: U4.12 (GPIO9); also elsewhere on the board
COL_7: U4.8 (GPIO6); also elsewhere on the board
COL_8: U4.7 (GPIO5); also elsewhere on the board
COL_9: U4.6 (GPIO4); also elsewhere on the board
COL_10: U4.5 (GPIO3); also elsewhere on the board
COL_11: U4.4 (GPIO2); also elsewhere on the board
GND: C3.2, C4.1, C5.1, C6.2, C7.2, C8.2, C9.2, C10.2, C11.2, C12.2, C13.2, C14.2, C15.2, C16.2, SW1.1, SW2.1, U3.4 (GND), U4.19 (TESTEN), U4.57 (GND), Y1.2, Y1.4; also elsewhere on the board
unnamed: C4.2, U4.20 (XIN), Y1.3
unnamed: C5.2, R8.1, Y1.1
unnamed: R4.2, U4.47 (USB_DP)
unnamed: R5.2, U4.46 (USB_DM)
unnamed: R8.2, U4.21 (XOUT)
ROW_0: U4.40 (GPIO28_ADC2); also elsewhere on the board
ROW_1: U4.30 (GPIO19); also elsewhere on the board
ROW_2: U4.31 (GPIO20); also elsewhere on the board
ROW_3: U4.36 (GPIO24); also elsewhere on the board
ROW_4: U4.37 (GPIO25); also elsewhere on the board
STATE_LED: U4.39 (GPIO27_ADC1); also elsewhere on the board

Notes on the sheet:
Flash

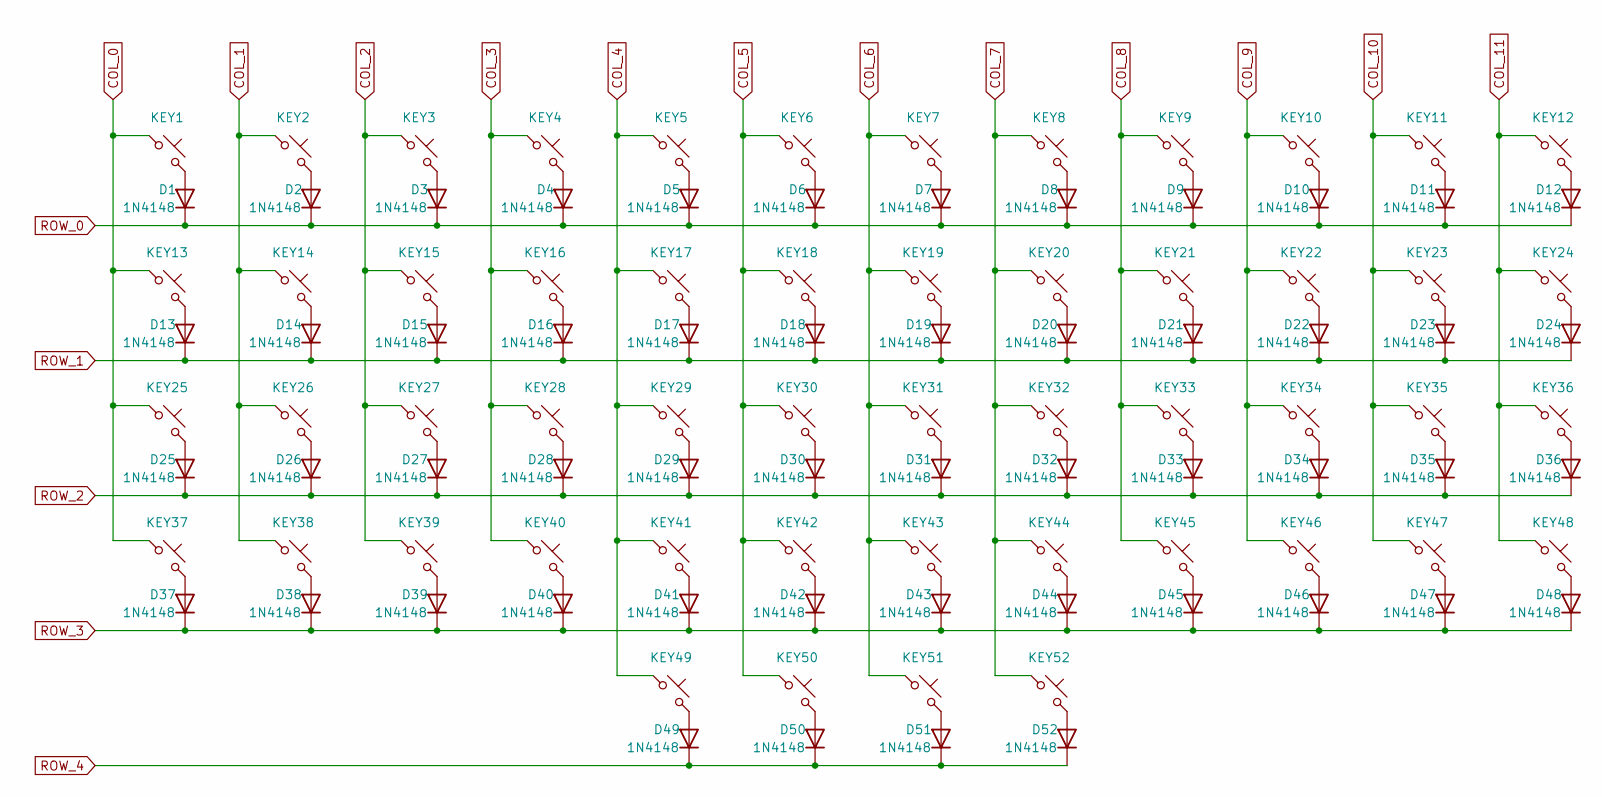
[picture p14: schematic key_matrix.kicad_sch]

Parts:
D1, D2, D3, D4, D5, D6, D7, D8, D9, D10, D11, D12, D13, D14, D15, D16, D17, D18, D19, D20, D21, D22, D23, D24, D25, D26, D27, D28, D29, D30, D31, D32, D33, D34, D35, D36, D37, D38, D39, D40, D41, D42, D43, D44, D45, D46, D47, D48, D49, D50, D51, D52: 1N4148; D_SOD-123; MFR. Part # 1N4148W; LCSC C81598
KEY1, KEY2, KEY3, KEY4, KEY5, KEY6, KEY7, KEY8, KEY9, KEY10, KEY11, KEY12, KEY13, KEY14, KEY15, KEY16, KEY17, KEY18, KEY19, KEY20, KEY21, KEY22, KEY23, KEY24, KEY25, KEY26, KEY27, KEY28, KEY29, KEY30, KEY31, KEY32, KEY33, KEY34, KEY35, KEY36, KEY37, KEY38, KEY39, KEY40, KEY41, KEY42, KEY43, KEY44, KEY45, KEY46, KEY47, KEY48, KEY49, KEY50, KEY51, KEY52: SW_Push_45deg; Kailh_Choc_PG1350_THT_A

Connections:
COL_0: KEY1.1, KEY13.1, KEY25.1, KEY37.1; also elsewhere on the board
COL_1: KEY2.1, KEY14.1, KEY26.1, KEY38.1; also elsewhere on the board
COL_2: KEY3.1, KEY15.1, KEY27.1, KEY39.1; also elsewhere on the board
COL_3: KEY4.1, KEY16.1, KEY28.1, KEY40.1; also elsewhere on the board
COL_4: KEY5.1, KEY17.1, KEY29.1, KEY41.1, KEY49.1; also elsewhere on the board
COL_5: KEY6.1, KEY18.1, KEY30.1, KEY42.1, KEY50.1; also elsewhere on the board
COL_6: KEY7.1, KEY19.1, KEY31.1, KEY43.1, KEY51.1; also elsewhere on the board
COL_7: KEY8.1, KEY20.1, KEY32.1, KEY44.1, KEY52.1; also elsewhere on the board
COL_8: KEY9.1, KEY21.1, KEY33.1, KEY45.1; also elsewhere on the board
COL_9: KEY10.1, KEY22.1, KEY34.1, KEY46.1; also elsewhere on the board
COL_10: KEY11.1, KEY23.1, KEY35.1, KEY47.1; also elsewhere on the board
COL_11: KEY12.1, KEY24.1, KEY36.1, KEY48.1; also elsewhere on the board
unnamed: D1.2 (A), KEY1.2
unnamed: D2.2 (A), KEY2.2
unnamed: D3.2 (A), KEY3.2
unnamed: D4.2 (A), KEY4.2
unnamed: D5.2 (A), KEY5.2
unnamed: D6.2 (A), KEY6.2
unnamed: D7.2 (A), KEY7.2
unnamed: D8.2 (A), KEY8.2
unnamed: D9.2 (A), KEY9.2
unnamed: D10.2 (A), KEY10.2
unnamed: D11.2 (A), KEY11.2
unnamed: D12.2 (A), KEY12.2
unnamed: D13.2 (A), KEY13.2
unnamed: D14.2 (A), KEY14.2
unnamed: D15.2 (A), KEY15.2
unnamed: D16.2 (A), KEY16.2
unnamed: D17.2 (A), KEY17.2
unnamed: D18.2 (A), KEY18.2
unnamed: D19.2 (A), KEY19.2
unnamed: D20.2 (A), KEY20.2
unnamed: D21.2 (A), KEY21.2
unnamed: D22.2 (A), KEY22.2
unnamed: D23.2 (A), KEY23.2
unnamed: D24.2 (A), KEY24.2
unnamed: D25.2 (A), KEY25.2
unnamed: D26.2 (A), KEY26.2
unnamed: D27.2 (A), KEY27.2
unnamed: D28.2 (A), KEY28.2
unnamed: D29.2 (A), KEY29.2
unnamed: D30.2 (A), KEY30.2
unnamed: D31.2 (A), KEY31.2
unnamed: D32.2 (A), KEY32.2
unnamed: D33.2 (A), KEY33.2
unnamed: D34.2 (A), KEY34.2
unnamed: D35.2 (A), KEY35.2
unnamed: D36.2 (A), KEY36.2
unnamed: D37.2 (A), KEY37.2
unnamed: D38.2 (A), KEY38.2
unnamed: D39.2 (A), KEY39.2
unnamed: D40.2 (A), KEY40.2
unnamed: D41.2 (A), KEY41.2
unnamed: D42.2 (A), KEY42.2
unnamed: D43.2 (A), KEY43.2
unnamed: D44.2 (A), KEY44.2
unnamed: D45.2 (A), KEY45.2
unnamed: D46.2 (A), KEY46.2
unnamed: D47.2 (A), KEY47.2
unnamed: D48.2 (A), KEY48.2
unnamed: D49.2 (A), KEY49.2
unnamed: D50.2 (A), KEY50.2
unnamed: D51.2 (A), KEY51.2
unnamed: D52.2 (A), KEY52.2
ROW_0: D1.1 (K), D2.1 (K), D3.1 (K), D4.1 (K), D5.1 (K), D6.1 (K), D7.1 (K), D8.1 (K), D9.1 (K), D10.1 (K), D11.1 (K), D12.1 (K); also elsewhere on the board
ROW_1: D13.1 (K), D14.1 (K), D15.1 (K), D16.1 (K), D17.1 (K), D18.1 (K), D19.1 (K), D20.1 (K), D21.1 (K), D22.1 (K), D23.1 (K), D24.1 (K); also elsewhere on the board
ROW_2: D25.1 (K), D26.1 (K), D27.1 (K), D28.1 (K), D29.1 (K), D30.1 (K), D31.1 (K), D32.1 (K), D33.1 (K), D34.1 (K), D35.1 (K), D36.1 (K); also elsewhere on the board
ROW_3: D37.1 (K), D38.1 (K), D39.1 (K), D40.1 (K), D41.1 (K), D42.1 (K), D43.1 (K), D44.1 (K), D45.1 (K), D46.1 (K), D47.1 (K), D48.1 (K); also elsewhere on the board
ROW_4: D49.1 (K), D50.1 (K), D51.1 (K), D52.1 (K); also elsewhere on the board

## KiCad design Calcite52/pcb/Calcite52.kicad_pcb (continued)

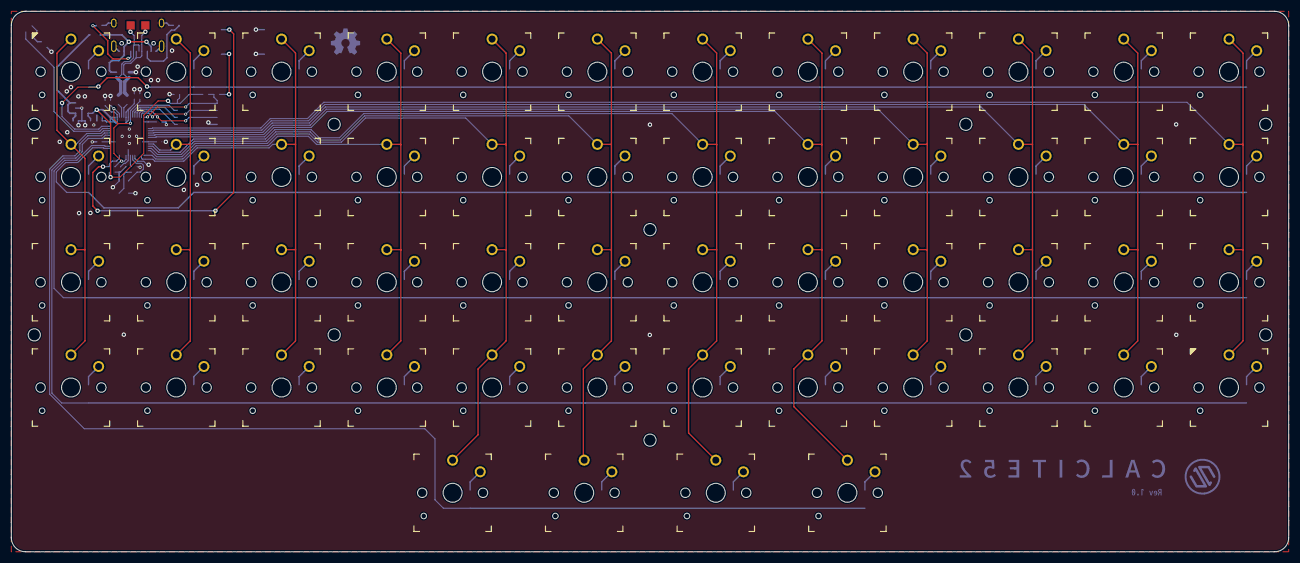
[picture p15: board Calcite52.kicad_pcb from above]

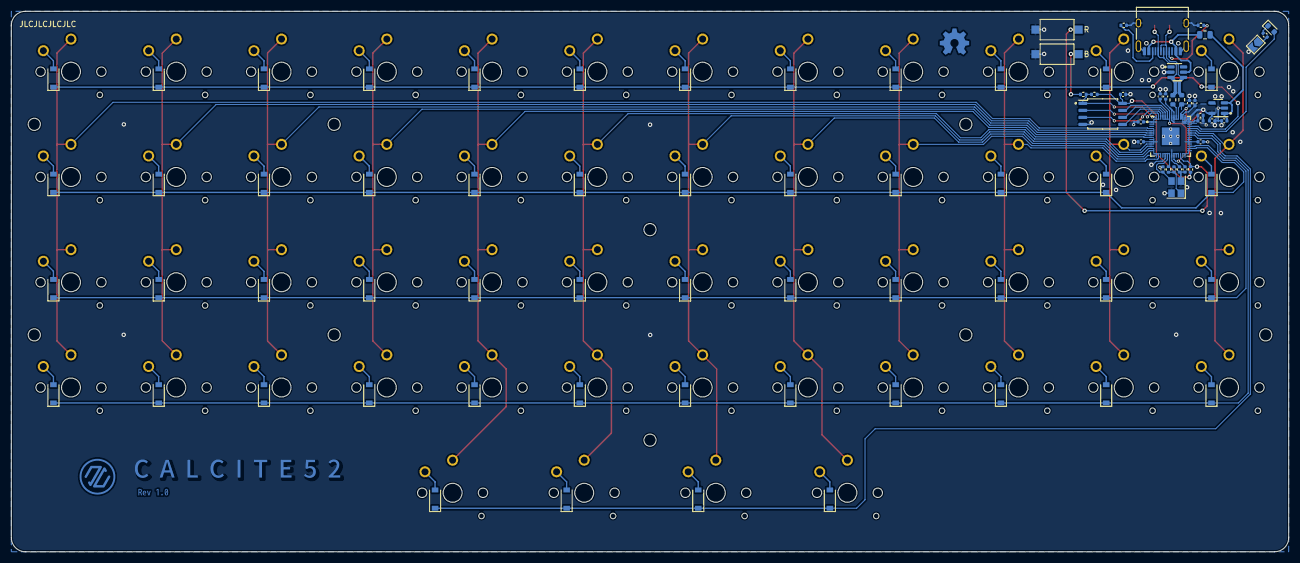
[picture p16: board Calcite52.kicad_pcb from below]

Board: 2 copper layers, 231.1 x 97.8 mm, 153 parts (89 on the bottom side), 94 nets.

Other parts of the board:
kibuzzard-63E64B4D: G***; kibuzzard-63E64B4D

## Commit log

2023-02-05 Add KiCad project
    [Fula52.kicad_pcb, Fula52.kicad_sch]
2023-02-05 Add submodule-key-switches.putty
2023-02-08 Update PCB layout, basically finished
    [Fula52.kicad_pcb, Fula52.kicad_sch, RP2040.kicad_sch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]
2023-02-09 full routed
    [Fula52.kicad_pcb, Fula52.kicad_sch, RP2040.kicad_sch]
2023-02-09 Rename, from Fula52 to Calcite52
    [Fula52.kicad_pcb, Fula52.kicad_sch]
2023-02-09 Update layout
    [Calcite52.kicad_pcb, Calcite52.kicad_sch, RP2040.kicad_sch]
2023-02-10 Update layout and logo
    [Calcite52.kicad_pcb, Calcite52.kicad_sch, RP2040.kicad_sch]
2023-03-03 Update BOM
    [Calcite52.kicad_pcb, Calcite52.kicad_sch, RP2040.kicad_sch]
2023-03-08 Add PCB center mark at "User.4" layer
    [Calcite52.kicad_pcb]
2023-03-08 Add case FreeCAD 3D model
    [Calcite52_keyboard_case.FCStd]
2023-03-15 Add case 30 model
    [Calcite52_keyboard_case.FCStd]
2023-03-16 Update case
    [Calcite52_keyboard_case.FCStd]
2023-04-29 Add project footprint library table
2023-04-29 Update KiCad files from `v6.0.8` to `v7.0.2`
    [Calcite52.kicad_pcb, Calcite52.kicad_sch, RP2040.kicad_sch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]
2023-07-06 Move Calcite52 files
    [Calcite52.kicad_pcb, Calcite52.kicad_sch, Calcite52_keyboard_case.FCStd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]
2023-07-06 Created Calcite60
    [Calcite60.kicad_pcb, Calcite60.kicad_sch, RP2040.kicad_sch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]
2023-07-06 Update footprint libraries path
2023-07-07 Reduce the size of the USB protrusion
    [Calcite60.kicad_pcb]
2023-07-07 Update board size
2023-07-08 Add calcite60 case
    [calcite60_case_bottom.dxf, calcite60_case_top.step]
2023-11-01 Update Calcite60 Rev2
    [Calcite60.kicad_pcb, Calcite60.kicad_sch, RP2040.kicad_sch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]
2024-01-06 Update board setup
2024-01-14 Update LICENSE
    [Calcite52.kicad_pcb, Calcite52.kicad_sch, Calcite60.kicad_pcb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]
2024-01-26 Add Calcite52 case
    [Calcite52_3dp_case.FCStd, Calcite52_cnc_case.step]
2024-04-17 Update switch footprint from TS-1064S to TS1064SA
    [Calcite60.kicad_sch, key_matrix.kicad_sch, mcu.kicad_sch]
2025-04-26 Add PCBA Calaite60
    [Calcite60.kicad_pcb, Calcite60.kicad_sch, RP2040.kicad_sch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]

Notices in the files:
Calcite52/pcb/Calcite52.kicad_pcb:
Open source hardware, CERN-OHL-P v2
